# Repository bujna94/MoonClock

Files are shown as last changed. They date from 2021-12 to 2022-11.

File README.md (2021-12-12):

### Hi there, I'm Pavol 👋 

Instagram Follow (https://www.instagram.com/pavols_lab/)

### MoonClock website - https://moonclock.com

## You have received and unboxed your MoonClock. Congratulations!

What now?

1. Plug MoonClock into your computer with provided USB-C cable. It will appear as a standard USB drive called "MOONCLOCK".

2. Open "secrets.py" with a text editor such as notepad and replace "WIFI_SSID" and "WIFI_PASSWORD" with your WiFi details and save.

3. Wait ~2minutes until Bitcoin price will appear on the MoonClock device.

That's all!

## Want more Crypto or just adjust the settings?

We all love Bitcoin, sure, but maybe you want to see the current price in another currency or completely another Crypto? No problem. MoonClock is ready for that!

1. Plug MoonClock into your computer with provided USB-C cable. It will appear as a standard USB drive called "MOONCLOCK".

2. Remove all files & folders from the "MOONCLOCK" drive.

3. Configure your cryptocurrencies in conf.py and copy the content of the CYCLE folder to the "MOONCLOCK" USB drive. (Don't forget to change your WiFi details again in the "secrets.py" file if you have to)

Wait ~2 minutes until new crypto will be shown on MoonClock.

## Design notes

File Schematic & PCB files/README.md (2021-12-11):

### The new schematic and PCB design

### Schematic

These are the final schematics using ESP32-S2.

### Main Board:
Schematic Main Board (https://www.moonclock.com/post/article-5-the-new-pcb-design)

### USB Board Schematic:
Schematic USB Board (https://www.moonclock.com/post/article-5-the-new-pcb-design)

### PCB Design

Here you can see the PCB design currently in manufacture 

### Main Board:
Schematic (https://www.moonclock.com/post/article-5-the-new-pcb-design)

### USB Board:
Schematic (https://www.moonclock.com/post/article-5-the-new-pcb-design)

### PCB view

This is the PCB view from OSH Park (but will be manufactured by JLCPCB).

### Main Board:
Schematic (https://www.moonclock.com/post/article-5-the-new-pcb-design)

### USB Board:
Schematic (https://www.moonclock.com/post/article-5-the-new-pcb-design)

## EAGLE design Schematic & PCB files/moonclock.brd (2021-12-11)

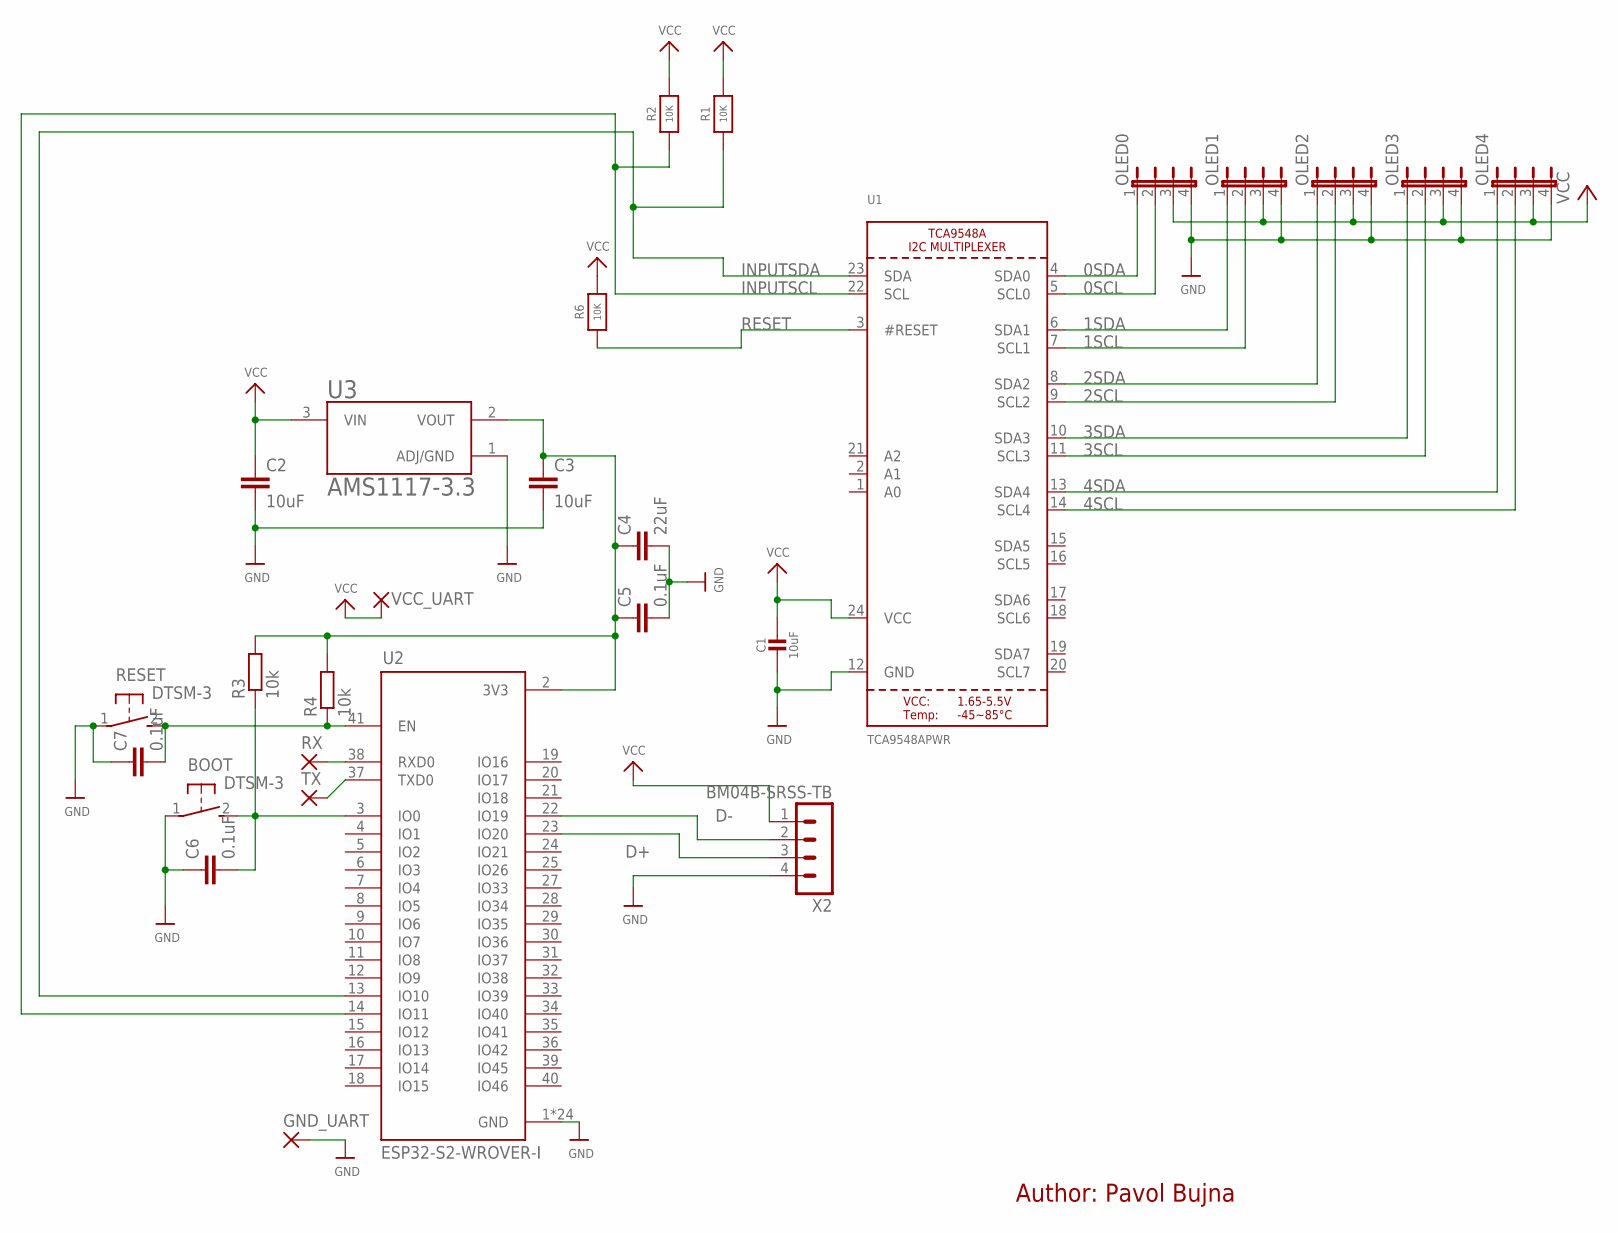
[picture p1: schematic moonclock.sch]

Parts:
BOOT: DTSM-3
C1: 10uF; 0805-NO
C2, C3: 10uF; C0805
C4: 22uF; C0805
C5, C6, C7: 0.1uF; C0805
GND_UART: SMD2; SMD1,27-2,54
OLED0, OLED1, OLED2, OLED3, OLED4: JP4E; JP4
R1, R2: 10K; 0805-NO
R3, R4: 10k; R0805
R6: 10K; _0805MP
RESET: DTSM-3
RX: SMD2; SMD1,27-2,54
TX: SMD2; SMD1,27-2,54
U1: TCA9548APWR; TSSOP24
U2: ESP32-S2-WROVER-I
U3: AMS1117-3.3; SOT229P700X180-4N
VCC_UART: SMD2; SMD1,27-2,54
X2: BM04B-SRSS-TB

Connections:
0SCL: OLED0.2, U1.5 (SCL0)
0SDA: OLED0.1, U1.4 (SDA0)
1SCL: OLED1.2, U1.7 (SCL1)
1SDA: OLED1.1, U1.6 (SDA1)
2SCL: OLED2.2, U1.9 (SCL2)
2SDA: OLED2.1, U1.8 (SDA2)
3SCL: OLED3.2, U1.11 (SCL3)
3SDA: OLED3.1, U1.10 (SDA3)
4SCL: OLED4.2, U1.14 (SCL4)
4SDA: OLED4.1, U1.13 (SDA4)
D+: U2.23 (IO20), X2.3
D-: U2.22 (IO19), X2.2
GND: BOOT.1, C1.2, C2.2, C3.2, C4.2, C5.2, C6.1, C7.1, GND_UART.1, OLED0.4, OLED1.4, OLED2.4, OLED3.4, OLED4.4, RESET.1, U1.12 (GND), U2.1 (GND), U2.26 (GND), U2.42 (GND), U2.43.1 (GND), U2.43.2 (GND), U2.43.3 (GND), U2.43.4 (GND), U2.43.5 (GND), U2.43.6 (GND), U2.43.7 (GND), U2.43.8 (GND), U2.43.9 (GND), U2.43.10 (GND), U2.43.11 (GND), U2.43.12 (GND), U2.43.13 (GND), U2.43.14 (GND), U2.43.15 (GND), U2.43.16 (GND), U2.43.17 (GND), U2.43.18 (GND), U2.43.19 (GND), U2.43.20 (GND), U2.43.21 (GND), U3.1 (ADJ/GND), X2.4
INPUTSCL: R2.1, U1.22 (SCL), U2.14 (IO11)
INPUTSDA: R1.1, U1.23 (SDA), U2.13 (IO10)
unnamed: TX.1, U2.37 (TXD0)
unnamed: RX.1, U2.38 (RXD0)
unnamed: C3.1, C4.1, C5.1, R3.2, R4.2, U2.2 (3V3), U3.2 (VOUT)
unnamed: BOOT.2, C6.2, R3.1, U2.3 (IO0)
unnamed: C7.2, R4.1, RESET.2, U2.41 (EN)
RESET: R6.1, U1.3 (#RESET)
VCC: C1.1, C2.1, OLED0.3, OLED1.3, OLED2.3, OLED3.3, OLED4.3, R1.2, R2.2, R6.2, U1.24 (VCC), U3.3 (VIN), VCC_UART.1, X2.1

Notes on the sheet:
Author: Pavol Bujna

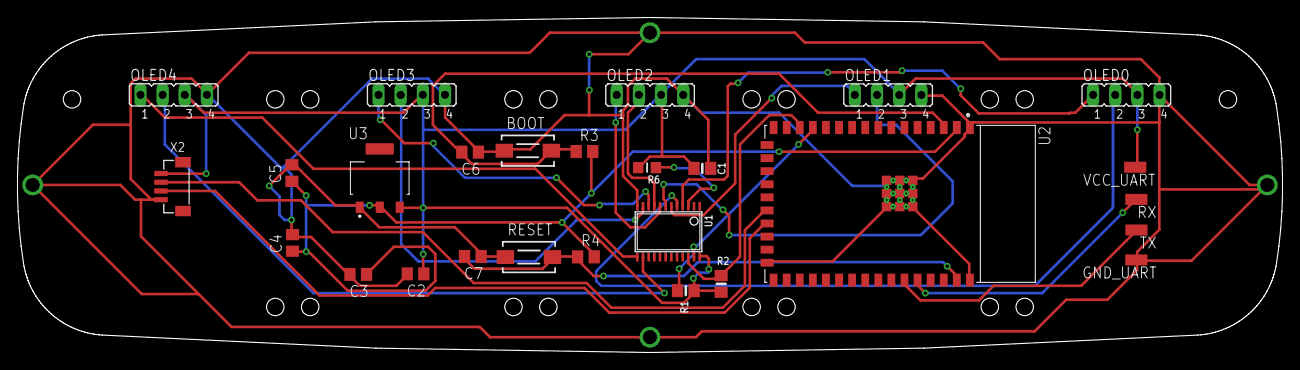
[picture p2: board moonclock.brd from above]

Board: 2 copper layers, 145.0 x 38.4 mm, 27 parts (0 on the bottom side), 22 nets.

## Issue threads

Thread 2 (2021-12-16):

Display stops updating without any error indication

zdeseb, 2021-12-16:
It occured to me that MoonClock froze with the same value on the display.
When this occurs, user does not know that there is a problem and that the displayed number could be few hours or days old.

Of-course solution is quite simple un/plug the power but the problem is that you do not have any way to realize that you should do that :-)

BTW: I saw in the code many print() statements but don't know how to get them :-)

Zdenek

the-papi, 2021-12-17:
If you have Linux, you can read the output of `print()` using `screen /dev/ttyACM0`. Can you provide it?

gorrdy, 2021-12-18:
This is a bug that happens sometimes. It is probably caused by exception in the python code. Solutuon is to check the code where these exceptions can happen and fix it there.

Would it be possible to have the whole cycle in code.py in python's 'try'? It would just reset the moonclock except of stopping it.

the-papi, 2021-12-18:
> Would it be possible to have the whole cycle in code.py in python's 'try'?
It's a possible "solution", but it's fucking ugly. However, it may work as a temporary workaround before merging #3.

zdeseb, 2021-12-18:
> It's a possible "solution", but it's fucking ugly. However, it may work as a temporary workaround before merging #3.

I am glad that I've not started rewriting the code yet as I see how much work has already been done :-)
And the code is definitely worth rewriting but python is not among my native programming languages so I was lazy to do it.

I could try to catch the error (already realized how to connect to console output from my OS) but I guess that it would be waste of time because it could be anything (WIFI problem, temporarily unavailable internet connection or the API).

I will apply the proposed 'try' hotfix and am looking forward to the merge ;-)

zdeseb, 2021-12-22:
> It's a possible "solution", but it's fucking ugly. However, it may work as a temporary workaround before merging #3.

FYI @the-papi : I've tried to run [#3](https://github.com/bujna94/MoonClock/pull/3) version for a while (about one day) and ended with following error
```
Auto-reload is off.
Running in safe mode! Not running saved code.

You are in safe mode because:
CircuitPython core code crashed hard. Crikey!
Crash into the HardFault_Handler.
Please file an issue with the contents of your CIRCUITPY drive at
https://github.com/adafruit/circuitpython/issues
```

the-papi, 2021-12-22:
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

This is issue of the ESP32 (or circuitpython?). Sometimes it behaves strangely when copying new code, and I don't know why. It's not a problem of my code.

If your moonclock has been reformatted and is now labeled CIRCUITPY instead of MOONCLOCK, don't worry. Mine too. It has zero effect on functionality.

gorrdy, 2022-01-18:
This is probably solved by PR #7

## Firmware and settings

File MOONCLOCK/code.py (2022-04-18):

import requests
import adafruit_tca9548a
import board
import busio
import json
import microcontroller
import rtc
import socketpool
import ssl
import time
import traceback
import wifi

from datetime import RTC

from apps import *
from display import BetterSSD1306_I2C, DisplayGroup


display_group = None


def reset():
    if display_group:
        try:
            display_group.render_string('RESET', center=True, empty_as_transparent=False)
            display_group.show()
        except Exception:
            pass

    print("Resetting....")
    time.sleep(30)
    microcontroller.on_next_reset(microcontroller.RunMode.NORMAL)
    microcontroller.reset()


# Get wifi details and more from a secrets.py file
try:
    from secrets import secrets
except ImportError:
    print('WiFi secrets are kept in secrets.py, please add them there!')
    raise

WIDTH = 128
HEIGHT = 64

SDA = board.IO10
SCL = board.IO11

i2c = busio.I2C(SCL, SDA, frequency=1400000)

if i2c.try_lock():
    print('i2c.scan():' + str(i2c.scan()))
    i2c.unlock()

tca = adafruit_tca9548a.TCA9548A(i2c)
display_group = DisplayGroup(
    [BetterSSD1306_I2C(WIDTH, HEIGHT, tca[i]) for i in range(5)])

print('My MAC addr:', [hex(i) for i in wifi.radio.mac_address])

display_group.render_string('wifi setup', center=True)
display_group.show()
time.sleep(1)

# Get configuration from a conf.py file
try:
    with open('conf.json', 'r') as f:
        conf = json.loads(f.read())
except OSError:
    # Backward compatibility
    try:
        from conf import conf
    except Exception as e:
        print(e)
        display_group.render_string('CONF ERROR')
        display_group.show()
        raise
except Exception as e:
    print(e)
    display_group.render_string('CONF ERROR')
    display_group.show()
    raise

connected = False

display_group.clear()
display_group.render_string('WIFI  INIT', center=True)
display_group.show()

while not connected:
    fail_count = 0
    for wifi_conf in secrets:
        try:
            print('Connecting to {}'.format(wifi_conf['ssid']))
            display_group.clear()
            display_group.render_string('{0} {1}'.format(font.CHAR_WIFI, wifi_conf['ssid'][:8]), center=False)
            display_group.show()
            time.sleep(1)
            wifi.radio.connect(wifi_conf['ssid'], wifi_conf['password'])
            print('Connected to {}!'.format(wifi_conf['ssid']))
            print('My IP address is', wifi.radio.ipv4_address)
            display_group.clear()
            display_group.render_string('{0} '.format(font.CHAR_CHECK), center=True)
            display_group.show()
            connected = True
            break
        except ConnectionError:
            fail_count += 1
            print('Connection to {} has failed. Trying next ssid...'.format(wifi_conf['ssid']))
            display_group.clear()
            display_group.render_string('{0} '.format(font.CHAR_CROSS), center=True)
            display_group.show()
            time.sleep(1)

    if fail_count == len(secrets):
        display_group.clear()
        display_group.render_string('no wifi!', center=True)
        display_group.show()
        time.sleep(2)
        display_group.clear()
        display_group.render_string('scanning..', center=True)
        display_group.show()
        time.sleep(2)

pool = socketpool.SocketPool(wifi.radio)
requests_ = requests.Session(pool, ssl.create_default_context())

try:
    display_group.clear()
    display_group.render_string('TIME  INIT', center=True)
    display_group.show()
    rtc.set_time_source(RTC(requests_, pool))
except Exception as e:
    traceback.print_exception(type(e), e, e.__traceback__)
    reset()

APPS = {
    'auto_contrast': AutoContrastApp,
    'crypto': CryptoApp,
    'time': TimeApp,
    'blockheight': BlockHeight,
    'halving': Halving,
    'fees': Fees,
    'text': Text,
    'marketcap': MarketCap,
    'moscow_time': MoscowTime,
    'difficulty': Difficulty,
    'temperature': Temperature,
    'xpub': Xpub,
    'test': TestDisplay,
    'lnbits_wallet_balance': LnbitsWalletBalance,
}


def main():
    apps = []

    # Initialize all apps
    display_group.clear()
    display_group.render_string('APPS  INIT', center=True)
    display_group.show()
    for app_conf in conf['apps']:
        name = app_conf.pop('name')
        print('Initializing {} app'.format(name))

        try:
            apps.append(APPS[name](display_group, requests_, **app_conf))
        except KeyError:
            raise ValueError('Unknown app {}'.format(name))
        except Exception as e:
            print('Initialization of application {} has failed'.format(APPS[name].__name__))
            print(e)
            traceback.print_exception(type(e), e, e.__traceback__)

    # Run apps
    while True:
        for app in apps:
            try:
                print('Running {} app'.format(app.__class__.__name__))
                app.run()
            except Exception as e:
                print('Application {} has crashed'.format(app.__class__.__name__))
                print(e)
                traceback.print_exception(type(e), e, e.__traceback__)
                reset()


if __name__ == '__main__':
    main()

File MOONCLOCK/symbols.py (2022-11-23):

ALGORAND = ((128, 64), bytearray(b'\x00\x00\x00\x00\x00\x00\x00\x00\x00\x00\x00\x00\x00\x00\x00\x00\x00\x00\x00\x00\x00\x00\x00\x00\x00\x00\x00\x00\x00\x00\x00\x00\x00\x00\x00\x00\x00\x00\x00\x00\x00\x00\x00\x00\x00\x00\x00\x00\x00\x00\x00\x00\x00\x00\x00\x00\x00\x00\x00\x00\x00\x00\x00\x00\x80\xc0\xf0\xf8\xfe\xff\xff\xff\xff\xff\xff\xff\xff\xff\xff\xfc\xf0\x00\x00\x00\x00\x00\x00\x00\x00\x00\x00\x00\x00\x00\x00\x00\x00\x00\x00\x00\x00\x00\x00\x00\x00\x00\x00\x00\x00\x00\x00\x00\x00\x00\x00\x00\x00\x00\x00\x00\x00\x00\x00\x00\x00\x00\x00\x00\x00\x00\x00\x00\x00\x00\x00\x00\x00\x00\x00\x00\x00\x00\x00\x00\x00\x00\x00\x00\x00\x00\x00\x00\x00\x00\x00\x00\x00\x00\x00\x00\x00\x00\x00\x00\x00\x00\x00\x00\x00\x00\x00\x00\x00\x00\x00\x00\x00\x00\x00\x00\x00\x00\x00\x00\x00\x00\x00\x00\x80\xe0\xf8\xfc\xff\xff\xff\xff\xff\xff\xff\x7f\x1f\xff\xff\xff\xff\xff\xff\xff\xff\xff\xe0\x00\x00\x00\x00\x00\x00\x00\x00\x00\x00\x00\x00\x00\x00\x00\x00\x00\x00\x00\x00\x00\x00\x00\x00\x00\x00\x00\x00\x00\x00\x00\x00\x00\x00\x00\x00\x00\x00\x00\x00\x00\x00\x00\x00\x00\x00\x00\x00\x00\x00\x00\x00\x00\x00\x00\x00\x00\x00\x00\x00\x00\x00\x00\x00\x00\x00\x00\x00\x00\x00\x00\x00\x00\x00\x00\x00\x00\x00\x00\x00\x00\x00\x00\x00\x00\x00\x00\x00\x00\x00\x00\x00\x00\x00\x00\x00\x00\x00\x00\x00\x00\xc0\xf0\xfc\xfe\xff\xff\xff\xff\xff\xff\x7f?\x0f\x03\x00\x00\x00\x00\x0f?\xff\xff\xff\xff\xff\xff\xff\xff\xff\xff\xff\xff\xff?\x1f\x07\x03\x00\x00\x00\x00\x00\x00\x00\x00\x00\x00\x00\x00\x00\x00\x00\x00\x00\x00\x00\x00\x00\x00\x00\x00\x00\x00\x00\x00\x00\x00\x00\x00\x00\x00\x00\x00\x00\x00\x00\x00\x00\x00\x00\x00\x00\x00\x00\x00\x00\x00\x00\x00\x00\x00\x00\x00\x00\x00\x00\x00\x00\x00\x00\x00\x00\x00\x00\x00\x00\x00\x00\x00\x00\x00\x00\x00\x00\x00\x00\x00\x00\x00\x00\x00\x00\x00\xc0\xe0\xf8\xfe\xff\xff\xff\xff\xff\xff\xff?\x0f\x07\x01\x00\x00\x00\x00\x00\x00\x00\x00\xc0\xf0\xff\xff\xff\xff\xff\xff\xff\xff\xff\xff\xff\x83\x01\x00\x00\x00\x00\x00\x00\x00\x00\x00\x00\x00\x00\x00\x00\x00\x00\x00\x00\x00\x00\x00\x00\x00\x00\x00\x00\x00\x00\x00\x00\x00\x00\x00\x00\x00\x00\x00\x00\x00\x00\x00\x00\x00\x00\x00\x00\x00\x00\x00\x00\x00\x00\x00\x00\x00\x00\x00\x00\x00\x00\x00\x00\x00\x00\x00\x00\x00\x00\x00\x00\x00\x00\x00\x00\x00\x00\x00\x00\x00\x00\x00\x00\x00\x00\x00\x80\xe0\xf0\xfc\xff\xff\xff\xff\xff\xff\xff\x7f\x1f\x07\x03\x00\x00\x00\x00\x00\x00\x00\x00\x80\xe0\xf8\xfc\xff\xff\xff\xff\xff\xff\xff\xff\xff\xff\xff\xff\xff\xff\xff\xf8\x80\x00\x00\x00\x00\x00\x00\x00\x00\x00\x00\x00\x00\x00\x00\x00\x00\x00\x00\x00\x00\x00\x00\x00\x00\x00\x00\x00\x00\x00\x00\x00\x00\x00\x00\x00\x00\x00\x00\x00\x00\x00\x00\x00\x00\x00\x00\x00\x00\x00\x00\x00\x00\x00\x00\x00\x00\x00\x00\x00\x00\x00\x00\x00\x00\x00\x00\x00\x00\x00\x00\x00\x00\x00\x00\x00\x00\x00\x00\x00\x00\xc0\xf0\xf8\xfe\xff\xff\xff\xff\xff\xff\xff?\x0f\x03\x00\x00\x00\x00\x00\x00\x00\x00\x80\xc0\xf0\xfc\xff\xff\xff\xff\xff\xff\xff\x7f\x1f\x0f\x03\x01\x03?\xff\xff\xff\xff\xff\xff\xff\xff\xfe\xc0\x00\x00\x00\x00\x00\x00\x00\x00\x00\x00\x00\x00\x00\x00\x00\x00\x00\x00\x00\x00\x00\x00\x00\x00\x00\x00\x00\x00\x00\x00\x00\x00\x00\x00\x00\x00\x00\x00\x00\x00\x00\x00\x00\x00\x00\x00\x00\x00\x00\x00\x00\x00\x00\x00\x00\x00\x00\x00\x00\x00\x00\x00\x00\x00\x00\x00\x00\x00\x00\x00\x00\x00\x00\xc0\xe0\xf8\xfe\xff\xff\xff\xff\xff\xff\xff\x7f\x0f\x07\x01\x00\x00\x00\x00\x00\x00\x00\x00\xc0\xe0\xf8\xfe\xff\xff\xff\xff\xff\xff\xff?\x0f\x07\x01\x00\x00\x00\x00\x00\x00\x00\x01\x1f\xff\xff\xff\xff\xff\xff\xff\xff\xfc\xc0\x00\x00\x00\x00\x00\x00\x00\x00\x00\x00\x00\x00\x00\x00\x00\x00\x00\x00\x00\x00\x00\x00\x00\x00\x00\x00\x00\x00\x00\x00\x00\x00\x00\x00\x00\x00\x00\x00\x00\x00\x00\x00\x00\x00\x00\x00\x00\x00\x00\x00\x00\x00\x00\x00\x00\x00\x00\x00\x00\x00\x00\x00\x00\x00\x00\x00\x80\xe0\xf0\xfc\xff\xff\xff\xff\xff\xff\xff\x7f\x1f\x07\x03\x00\x00\x00\x00\x00\x00\x00\x00\x80\xe0\xf8\xfc\xff\xff\xff\xff\xff\xff\xff?\x1f\x07\x01\x00\x00\x00\x00\x00\x00\x00\x00\x00\x00\x00\x00\x00\x00\x01\x07\xff\xff\xff\xff\xff\xff\xff\xff\xfe\xe0\x00\x00\x00\x00\x00\x00\x00\x00\x00\x00\x00\x00\x00\x00\x00\x00\x00\x00\x00\x00\x00\x00\x00\x00\x00\x00\x00\x00\x00\x00\x00\x00'))
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

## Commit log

2021-12-10 Added Eagle schematic & PCB files
    [moonclock.brd, moonclock.sch, usb_board.brd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]
2021-12-12 console print fix
2021-12-15 Reworked config. Some minor bugfixes.
    [apps.py, code.py]
2021-12-15 Minor fixes. Changed BTC logo. Added conversion script from .bmp to moonclock format.
    [apps.py, code.py, symbols.py]
2021-12-15 Added time print
2021-12-17 Minor fixes and refactoring
    [apps.py, code.py, display.py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]
2021-12-18 Added font sources. Fixed number 3, 4, 5 and 7
    [font.py, symbols.py]
2021-12-19 Added wifi connection retry after fail
    [code.py]
2021-12-20 Added print_exception
2021-12-21 Increased I2C frequency to 1400000
2021-12-22 fix letters and add more symbols
    [font.py, symbols.py]
2021-12-22 fix price with 7 places, round to 4 decimals
    [apps.py]
2021-12-23 add wifi setup, fix logos with transparent spaces
    [code.py, display.py, font.py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]
2021-12-25 reload MC when app crashes
    [code.py]
2021-12-25 fix hexa numbers, format
    [code.py, font.py]
2021-12-25 add support for left, right, center alignment, fix halving string
    [apps.py, code.py, font.py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]
2021-12-29 add two more apps difficulty, temperature
2021-12-30 fix str_align to str_rjust
    [apps.py]
2022-01-02 fix weather app when some arg is None, add update frequency to CryptoApp
    [apps.py]
2022-01-04 fix missing symbols check and cross
    [font.py]
2022-01-09 Fixed app duration and update_frequency
    [apps.py]
2022-01-10 Removed debug print
2022-01-12 Replaced all https to http
    [apps.py]
2022-01-17 Probably fixed freezing? :thinking:
    [apps.py, code.py, datetime.py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]
2022-01-17 Added more debug print
2022-01-17 Added more debug prints
2022-11-23 Added logo of Monero
    Fix
    [font.py, logo.py, symbols.py]

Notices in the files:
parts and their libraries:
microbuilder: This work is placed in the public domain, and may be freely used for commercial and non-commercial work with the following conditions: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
